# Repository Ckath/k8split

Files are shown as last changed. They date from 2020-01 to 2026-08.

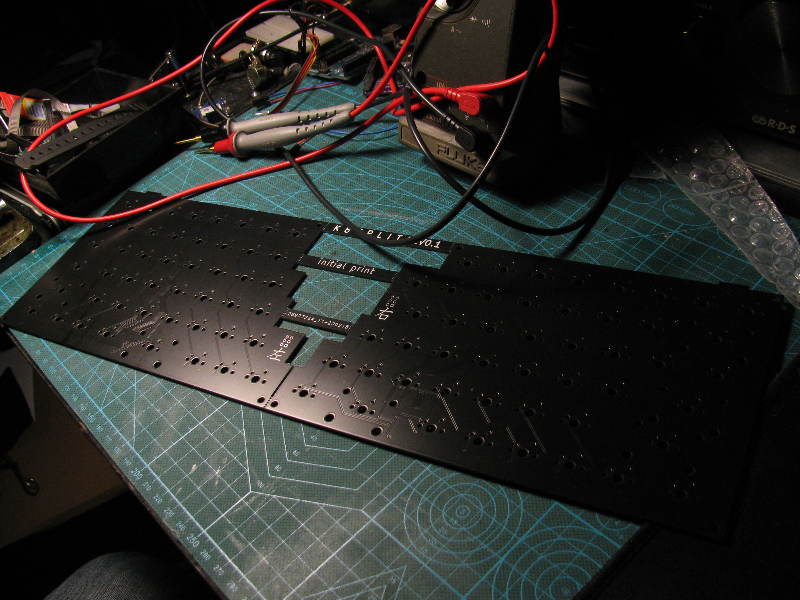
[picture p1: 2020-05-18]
k8split_board.jpg

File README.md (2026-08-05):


shoddy split keyboard for personal use, after ruining my [chinese split keyboard](http://xahlee.info/kbd/ly092_mini_keyboard.html) I attempted to recreate what I wanted from that, minus all the annoyances.

for the previous more scuffed and QMK version see [rev0.1](https://github.com/Ckath/k8split/tree/rev0.1)

## features
-  *normal* layout: 
	- no ortho
	- no lack of function row
	- no weird thumbclusters
	- plenty bonus keys to add what you miss
- no case or plate, only M3 holes
- halves are linked hardwired to central controller (over VGA)
- regular FULL SIZED USB PORT
- powered by TMK

## rev0.1->0.2 up/downgrades
- no more dual mcu nonsense
- no more QMK I'm not dealing with modern QMK
- no more smd 4 pin crystal suffering
- due to lack of pcb stabilizers for this formfactor: no more stabilizers
- cherry low profile switches
- boards themselves optimized for liquid damage mitigation, all throughhole for easy fixing

## pics
### keyboards
TODO
<!-- ![left](k8split_left.png) -->
<!-- ![right](k8split_right.png) -->
### pcb 
TODO
<!-- ![board](k8split_board.jpg) -->

## ordering
theres an `ORDER` folder in the pcb project, with all required files, dont honestly. if you want one I could probably send you one of my spare PCBs

### advice
keep in mind this is a personal board made just for myself, it's more up for reference/show than it is meant for people to actually use it. that said, some advice if you do think about making one:
- any still configured component part number is not updated, rev0.2 is made from what I had laying around and non pre assembled pcb
- to keep things easy I recommend a flat profile keycap set like dsa
- the nearly fully smd usb connector is a china find, you can find them on the regular places as "smd usb a female", the right ones should only have one shield pad on either side.
- the 'case' hardware used is a standard M3 standoff set, anything works.

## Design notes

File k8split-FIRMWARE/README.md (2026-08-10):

# TMK firmware
these are the minimal viable files for the tmk firmware to my best knowledge. attempted to be less horribly verbose in matrix.c implementation than most example boards, using only masks, avoiding needless extra functions etc.

## building/flashing
```
# if not already done, need this to get lufa repo inside tmk_core
git submodule update --init --recursive
# build and flash
make dfu
```

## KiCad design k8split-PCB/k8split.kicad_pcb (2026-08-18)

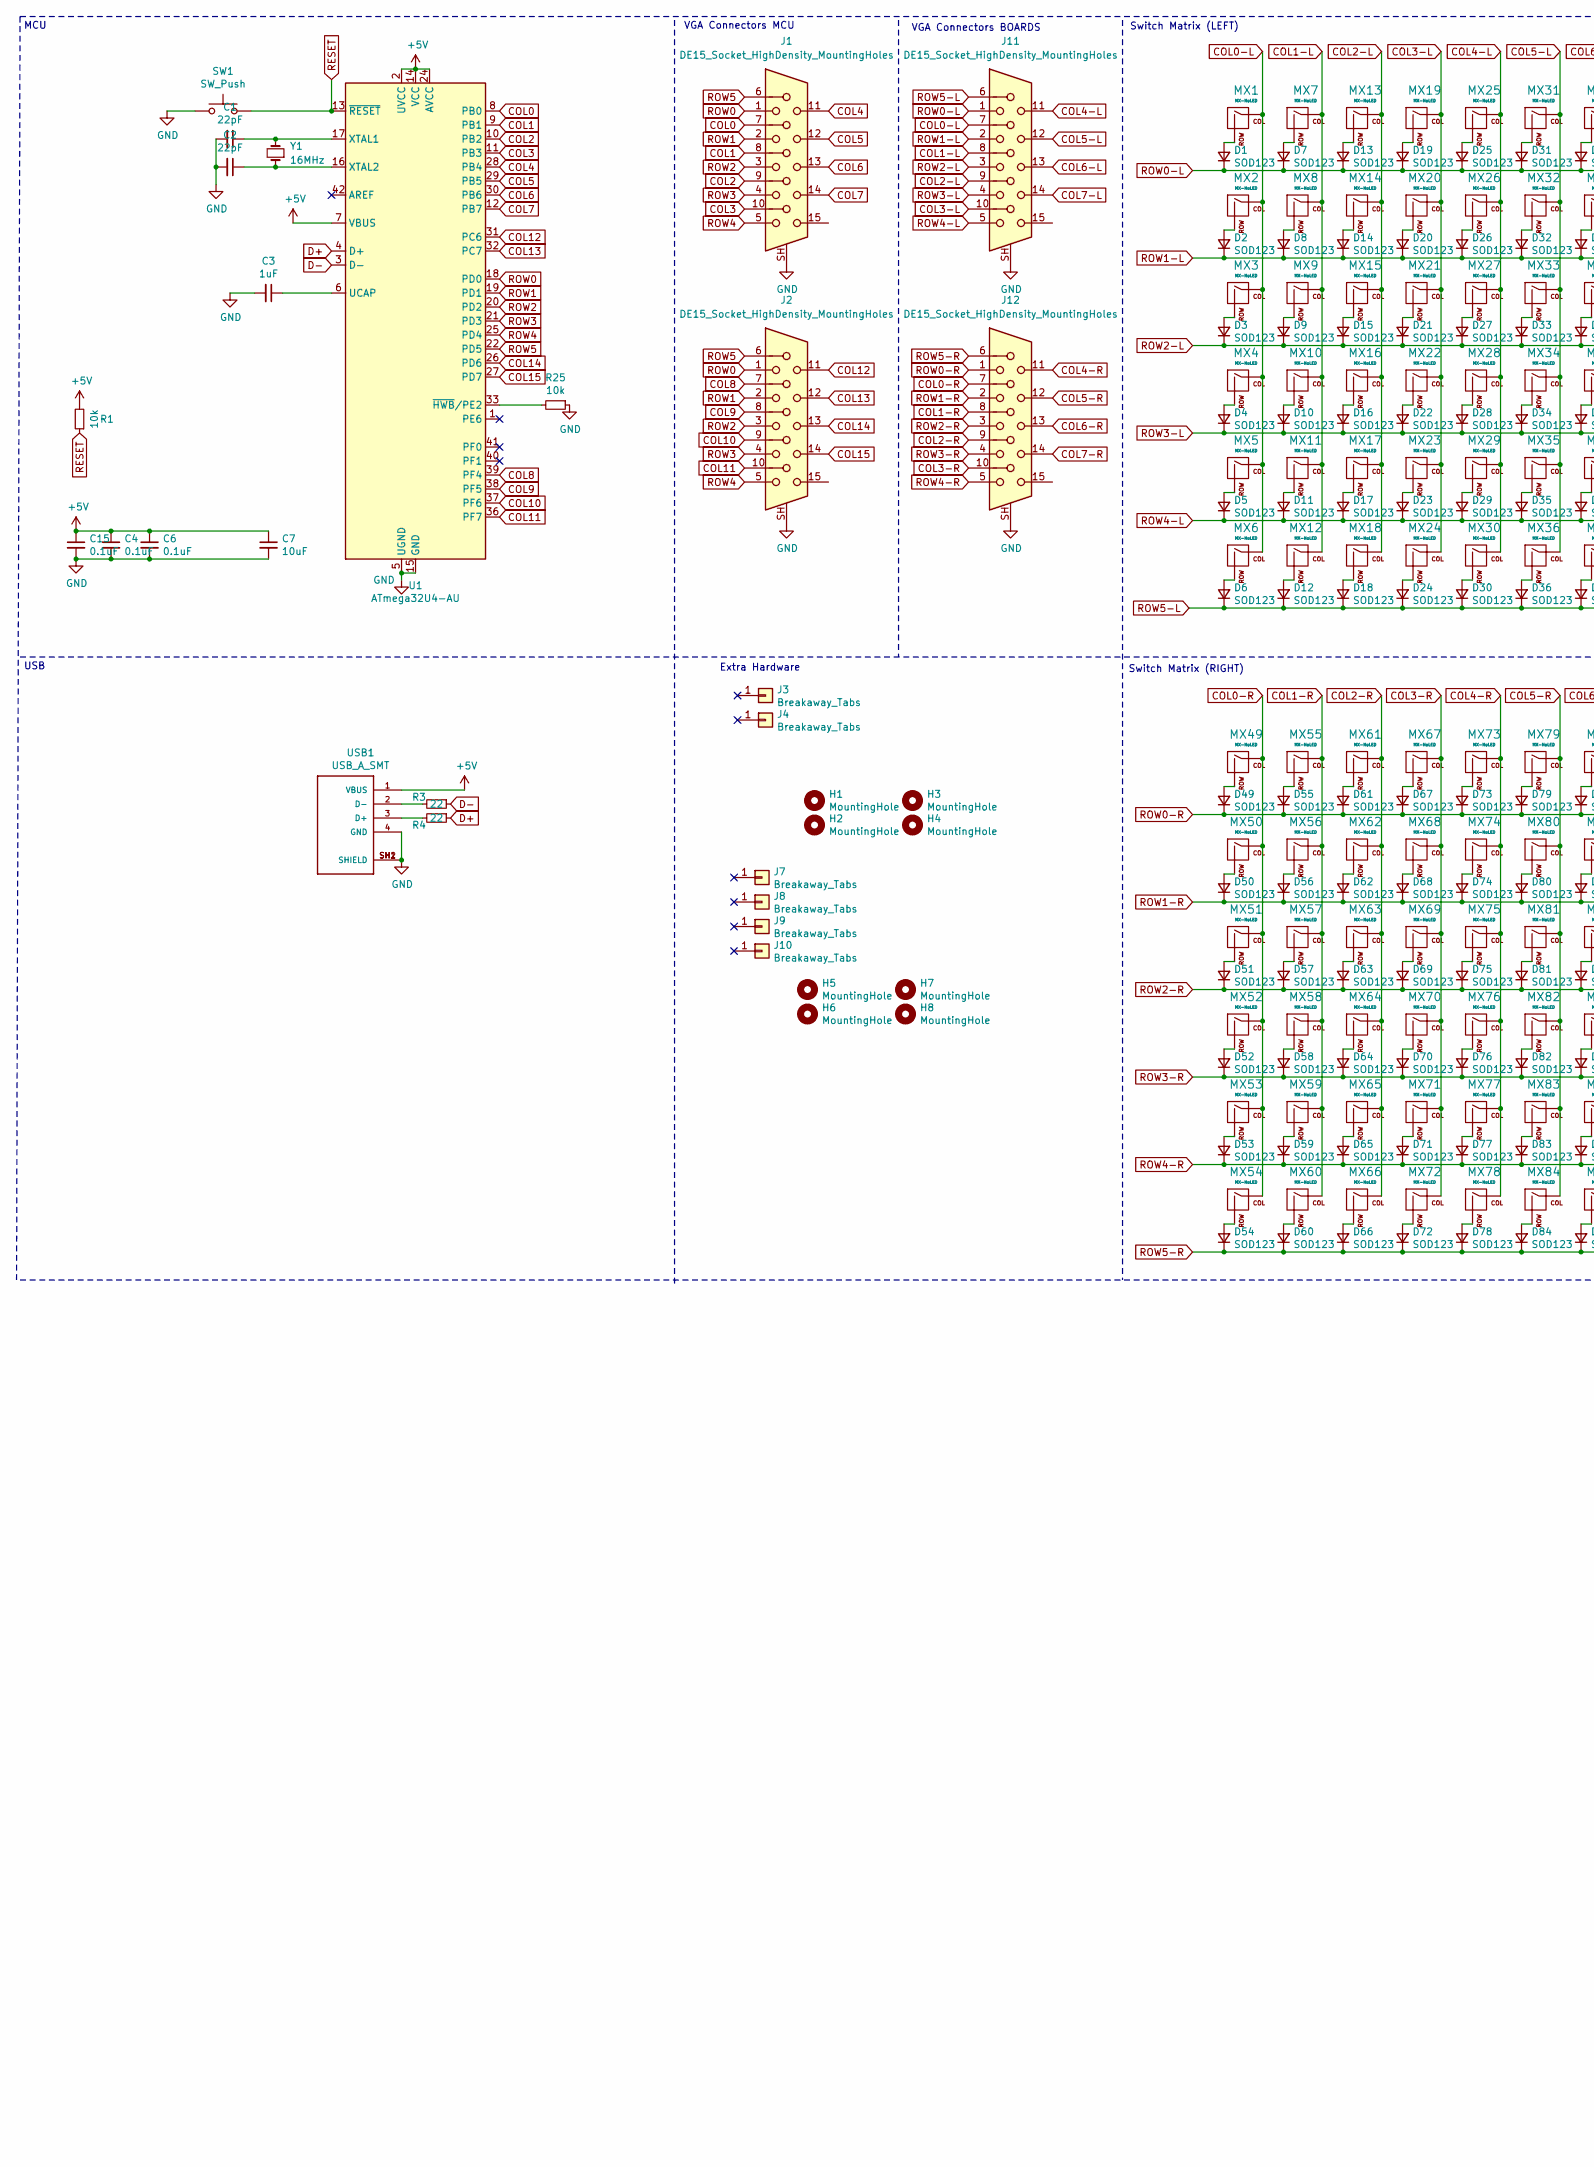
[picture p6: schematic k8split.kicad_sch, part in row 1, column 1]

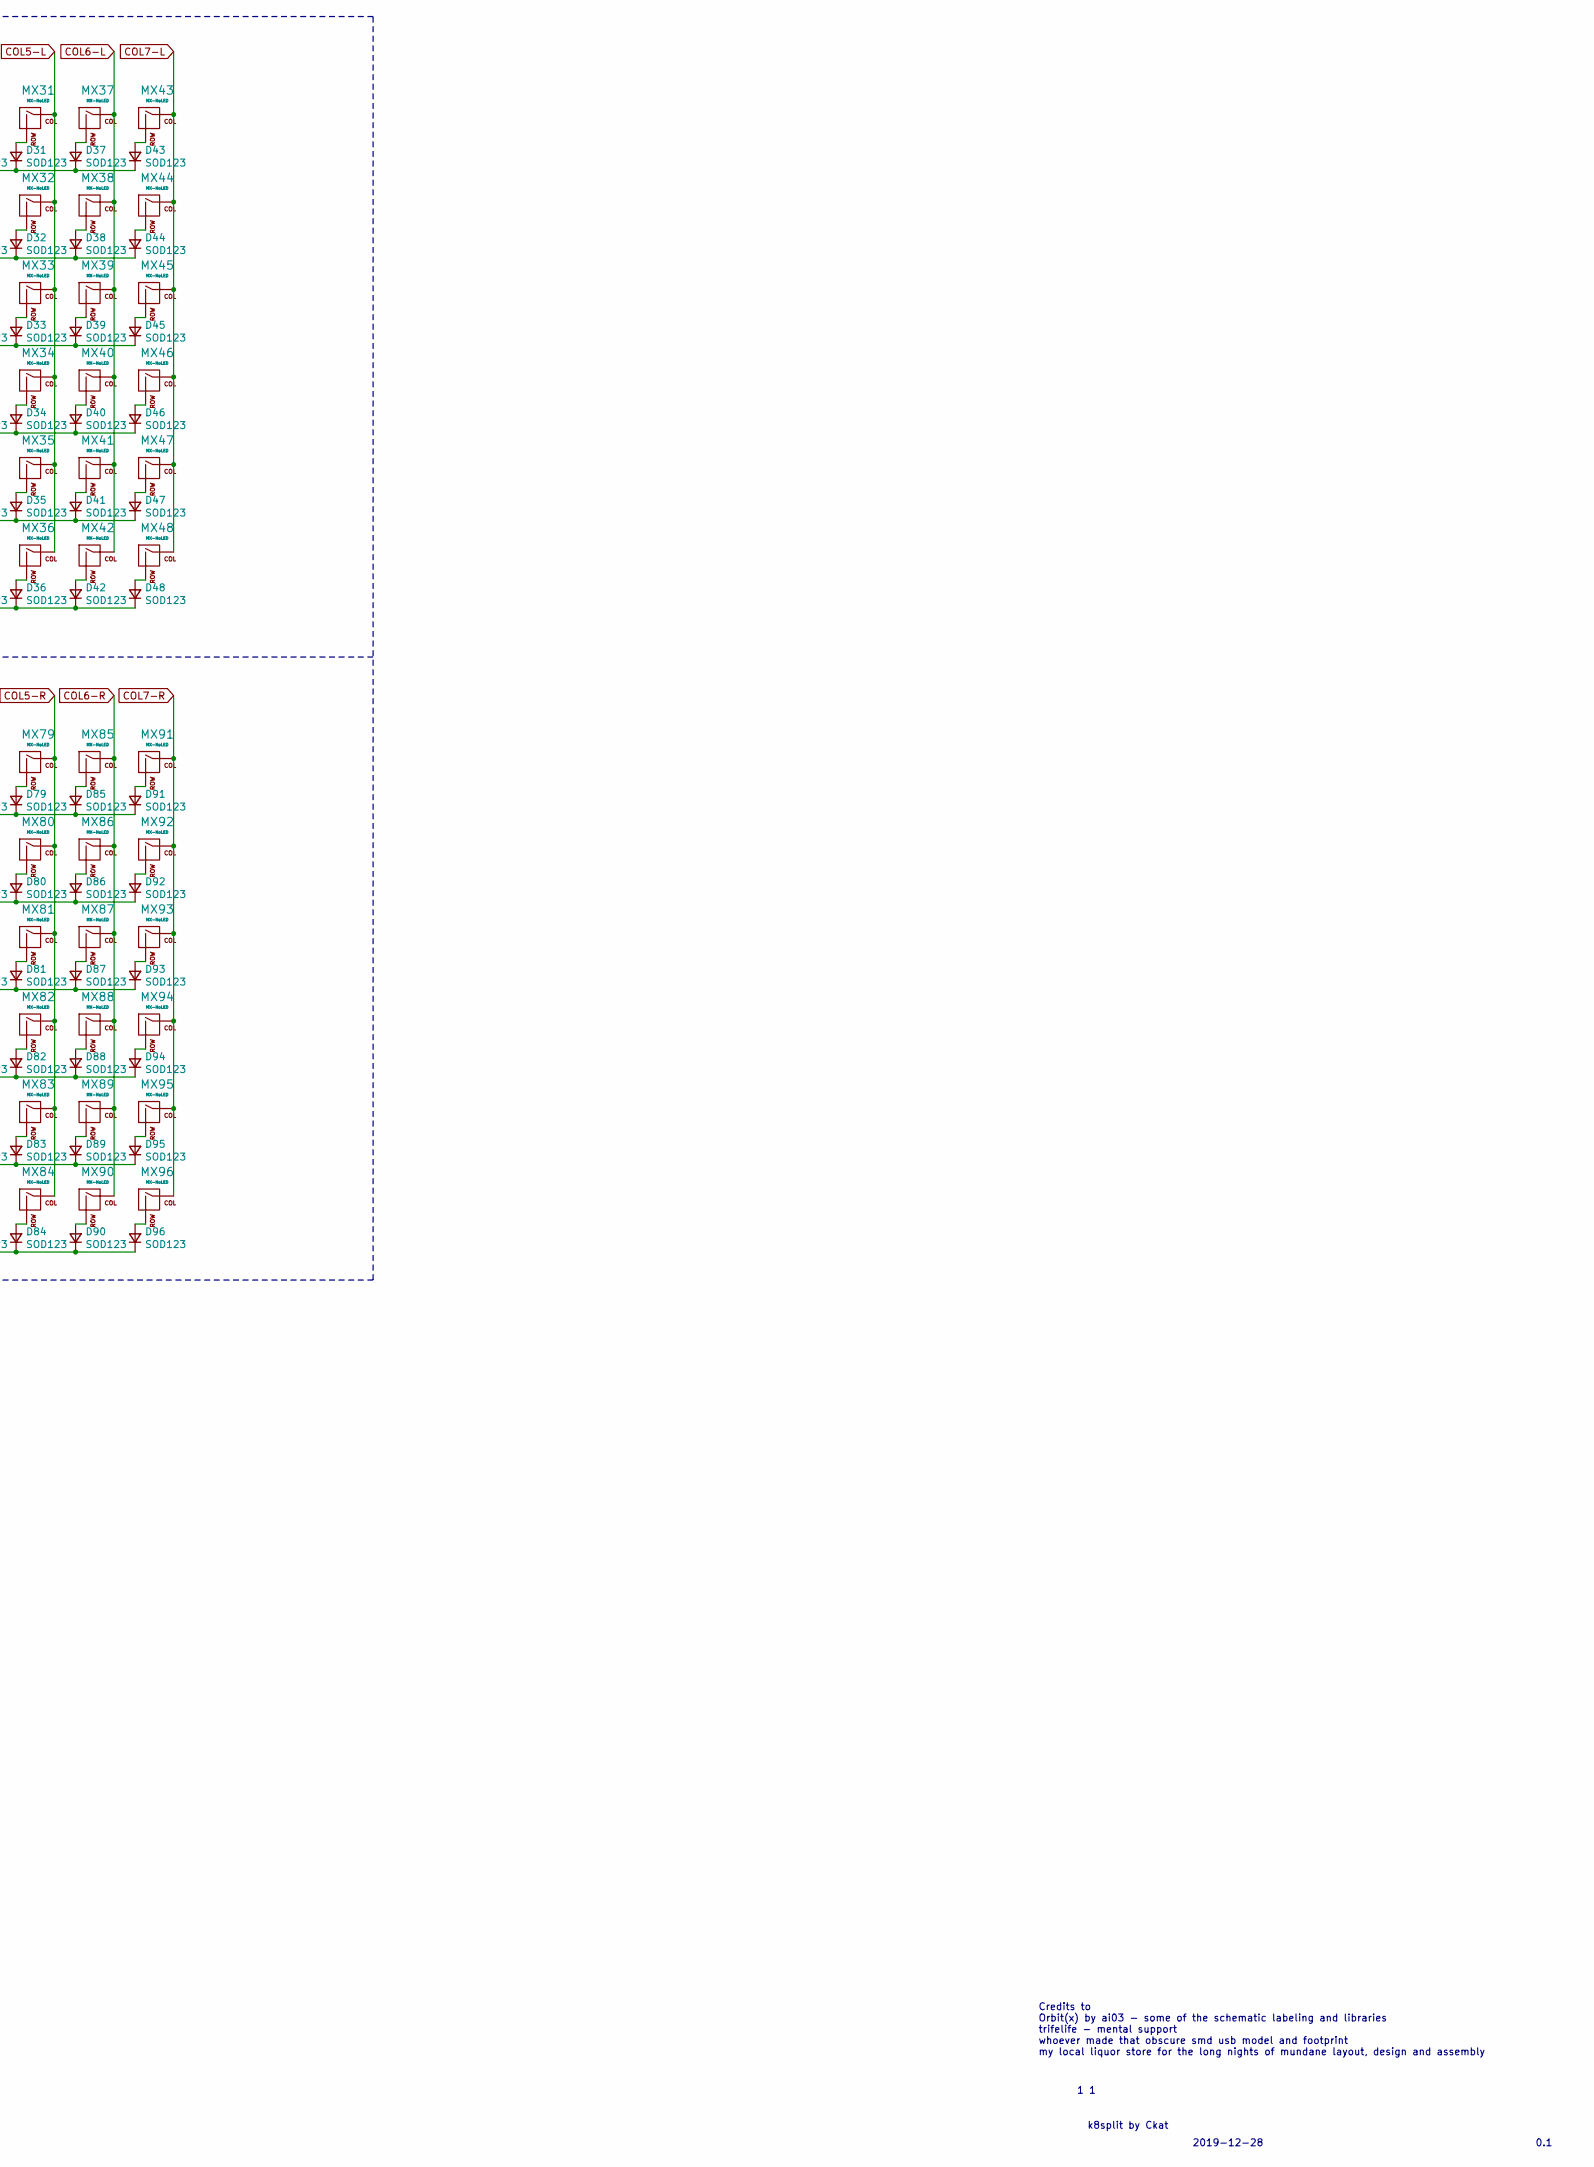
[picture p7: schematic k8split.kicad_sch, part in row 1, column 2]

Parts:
C1, C2: 22pF; C_0603_1608Metric
C3: 1uF; C_0603_1608Metric
C4, C6, C15: 0.1uF; C_0603_1608Metric
C7: 10uF; C_0603_1608Metric
D1, D2, D3, D4, D5, D6, D7, D8, D9, D10, D11, D12, D13, D14, D15, D16, D17, D18, D19, D20, D21, D22, D23, D24, D25, D26, D27, D28, D29, D30, D31, D32, D33, D34, D35, D36, D37, D38, D39, D40, D41, D42, D43, D44, D45, D46, D47, D48, D49, D50, D51, D52, D53, D54, D55, D56, D57, D58, D59, D60, D61, D62, D63, D64, D65, D66, D67, D68, D69, D70, D71, D72, D73, D74, D75, D76, D77, D78, D79, D80, D81, D82, D83, D84, D85, D86, D87, D88, D89, D90, D91, D92, D93, D94, D95, D96: SOD123; D_A-405_P10.16mm_Horizontal
H1, H2, H3, H4, H5, H6, H7, H8: MountingHole; MountingHole_3.2mm_M3
J1, J2, J11, J12: DE15_Socket_HighDensity_MountingHoles; DSUB-15-HD_Socket_Horizontal_P2.29x1.90mm_EdgePinOffset3.03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
J3, J4, J7, J8, J9, J10: Breakaway_Tabs; breakaway-mousebites
MX1, MX2, MX7, MX8, MX9, MX10, MX11, MX12, MX13, MX14, MX15, MX16, MX17, MX18, MX19, MX20, MX21, MX22, MX23, MX25, MX26, MX27, MX28, MX29, MX31, MX32, MX33, MX34, MX35, MX36, MX37, MX38, MX39, MX40, MX41, MX42, MX43, MX44, MX45, MX46, MX47, MX48, MX49, MX50, MX51, MX52, MX53, MX54, MX55, MX56, MX57, MX58, MX59, MX61, MX62, MX63, MX64, MX65, MX67, MX68, MX69, MX70, MX71, MX72, MX73, MX74, MX75, MX76, MX77, MX78, MX79, MX80, MX81, MX82, MX83, MX84, MX85, MX86, MX87, MX88, MX89, MX90, MX91: MX-NoLED; SW_choc_v2_1u
MX3, MX6, MX93, MX96: MX-NoLED; SW_choc_v2_1.5u
MX4: MX-NoLED; SW_choc_v2_1.75u
MX5, MX30, MX60, MX94: MX-NoLED; SW_choc_v2_2.25u
MX24, MX66: MX-NoLED; SW_choc_v2_1.25u
MX92: MX-NoLED; SW_choc_v2_2u
MX95: MX-NoLED; SW_choc_v2_2.75u
R1, R25: 10k; R_0603_1608Metric
R3, R4: 22; R_0603_1608Metric
SW1: SW_Push; SKQGADE010
U1: ATmega32U4-AU; TQFP-44_10x10mm_P0.8mm
USB1: USB_A_SMT; CUI_UJ2-AH-4-SMT
Y1: 16MHz; Crystal_HC49-4H_Vertical

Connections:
+5V: C4.1, C6.1, C7.1, C15.1, R1.2, U1.2 (UVCC), U1.7 (VBUS), U1.14 (VCC), U1.24 (AVCC), U1.34 (VCC), U1.44 (AVCC), USB1.1 (VBUS)
COL0: J1.7, U1.8 (PB0)
COL0-L: J11.7, MX1.1 (COL), MX2.1 (COL), MX3.1 (COL), MX4.1 (COL), MX5.1 (COL), MX6.1 (COL)
COL0-R: J12.7, MX49.1 (COL), MX50.1 (COL), MX51.1 (COL), MX52.1 (COL), MX53.1 (COL), MX54.1 (COL)
COL1: J1.8, U1.9 (PB1)
COL1-L: J11.8, MX7.1 (COL), MX8.1 (COL), MX9.1 (COL), MX10.1 (COL), MX11.1 (COL), MX12.1 (COL)
COL1-R: J12.8, MX55.1 (COL), MX56.1 (COL), MX57.1 (COL), MX58.1 (COL), MX59.1 (COL), MX60.1 (COL)
COL2: J1.9, U1.10 (PB2)
COL2-L: J11.9, MX13.1 (COL), MX14.1 (COL), MX15.1 (COL), MX16.1 (COL), MX17.1 (COL), MX18.1 (COL)
COL2-R: J12.9, MX61.1 (COL), MX62.1 (COL), MX63.1 (COL), MX64.1 (COL), MX65.1 (COL), MX66.1 (COL)
COL3: J1.10, U1.11 (PB3)
COL3-L: J11.10, MX19.1 (COL), MX20.1 (COL), MX21.1 (COL), MX22.1 (COL), MX23.1 (COL), MX24.1 (COL)
COL3-R: J12.10, MX67.1 (COL), MX68.1 (COL), MX69.1 (COL), MX70.1 (COL), MX71.1 (COL), MX72.1 (COL)
COL4: J1.11, U1.28 (PB4)
COL4-L: J11.11, MX25.1 (COL), MX26.1 (COL), MX27.1 (COL), MX28.1 (COL), MX29.1 (COL), MX30.1 (COL)
COL4-R: J12.11, MX73.1 (COL), MX74.1 (COL), MX75.1 (COL), MX76.1 (COL), MX77.1 (COL), MX78.1 (COL)
COL5: J1.12, U1.29 (PB5)
COL5-L: J11.12, MX31.1 (COL), MX32.1 (COL), MX33.1 (COL), MX34.1 (COL), MX35.1 (COL), MX36.1 (COL)
COL5-R: J12.12, MX79.1 (COL), MX80.1 (COL), MX81.1 (COL), MX82.1 (COL), MX83.1 (COL), MX84.1 (COL)
COL6: J1.13, U1.30 (PB6)
COL6-L: J11.13, MX37.1 (COL), MX38.1 (COL), MX39.1 (COL), MX40.1 (COL), MX41.1 (COL), MX42.1 (COL)
COL6-R: J12.13, MX85.1 (COL), MX86.1 (COL), MX87.1 (COL), MX88.1 (COL), MX89.1 (COL), MX90.1 (COL)
COL7: J1.14, U1.12 (PB7)
COL7-L: J11.14, MX43.1 (COL), MX44.1 (COL), MX45.1 (COL), MX46.1 (COL), MX47.1 (COL), MX48.1 (COL)
COL7-R: J12.14, MX91.1 (COL), MX92.1 (COL), MX93.1 (COL), MX94.1 (COL), MX95.1 (COL), MX96.1 (COL)
COL8: J2.7, U1.39 (PF4)
COL9: J2.8, U1.38 (PF5)
COL10: J2.9, U1.37 (PF6)
COL11: J2.10, U1.36 (PF7)
COL12: J2.11, U1.31 (PC6)
COL13: J2.12, U1.32 (PC7)
COL14: J2.13, U1.26 (PD6)
COL15: J2.14, U1.27 (PD7)
D+: R4.1, U1.4 (D+)
D-: R3.1, U1.3 (D-)
GND: C1.2, C2.2, C3.2, C4.2, C6.2, C7.2, C15.2, J1.SH, J2.SH, J11.SH, J12.SH, R25.1, SW1.1, U1.5 (UGND), U1.15 (GND), U1.23 (GND), U1.35 (GND), U1.43 (GND), USB1.4 (GND), USB1.SH1 (SHIELD), USB1.SH2 (SHIELD)
unnamed: D1.2 (A), MX1.2 (ROW)
unnamed: D2.2 (A), MX2.2 (ROW)
unnamed: D3.2 (A), MX3.2 (ROW)
unnamed: D4.2 (A), MX4.2 (ROW)
unnamed: D5.2 (A), MX5.2 (ROW)
unnamed: D6.2 (A), MX6.2 (ROW)
unnamed: D7.2 (A), MX7.2 (ROW)
unnamed: D8.2 (A), MX8.2 (ROW)
unnamed: D9.2 (A), MX9.2 (ROW)
unnamed: D10.2 (A), MX10.2 (ROW)
unnamed: D11.2 (A), MX11.2 (ROW)
unnamed: D12.2 (A), MX12.2 (ROW)
unnamed: D13.2 (A), MX13.2 (ROW)
unnamed: D14.2 (A), MX14.2 (ROW)
unnamed: D15.2 (A), MX15.2 (ROW)
unnamed: D16.2 (A), MX16.2 (ROW)
unnamed: D17.2 (A), MX17.2 (ROW)
unnamed: D18.2 (A), MX18.2 (ROW)
unnamed: D19.2 (A), MX19.2 (ROW)
unnamed: D20.2 (A), MX20.2 (ROW)
unnamed: D21.2 (A), MX21.2 (ROW)
unnamed: D22.2 (A), MX22.2 (ROW)
unnamed: D23.2 (A), MX23.2 (ROW)
unnamed: D24.2 (A), MX24.2 (ROW)
unnamed: D25.2 (A), MX25.2 (ROW)
unnamed: D26.2 (A), MX26.2 (ROW)
unnamed: D27.2 (A), MX27.2 (ROW)
unnamed: D28.2 (A), MX28.2 (ROW)
unnamed: D29.2 (A), MX29.2 (ROW)
unnamed: D30.2 (A), MX30.2 (ROW)
unnamed: D31.2 (A), MX31.2 (ROW)
unnamed: D32.2 (A), MX32.2 (ROW)
unnamed: D33.2 (A), MX33.2 (ROW)
unnamed: D34.2 (A), MX34.2 (ROW)
unnamed: D35.2 (A), MX35.2 (ROW)
unnamed: D36.2 (A), MX36.2 (ROW)
unnamed: D37.2 (A), MX37.2 (ROW)
unnamed: D38.2 (A), MX38.2 (ROW)
unnamed: D39.2 (A), MX39.2 (ROW)
unnamed: D40.2 (A), MX40.2 (ROW)
unnamed: D41.2 (A), MX41.2 (ROW)
unnamed: D42.2 (A), MX42.2 (ROW)
unnamed: D43.2 (A), MX43.2 (ROW)
unnamed: D44.2 (A), MX44.2 (ROW)
unnamed: D45.2 (A), MX45.2 (ROW)
unnamed: D46.2 (A), MX46.2 (ROW)
unnamed: D47.2 (A), MX47.2 (ROW)
unnamed: D48.2 (A), MX48.2 (ROW)
unnamed: D49.2 (A), MX49.2 (ROW)
unnamed: D50.2 (A), MX50.2 (ROW)
unnamed: D51.2 (A), MX51.2 (ROW)
unnamed: D52.2 (A), MX52.2 (ROW)
unnamed: D53.2 (A), MX53.2 (ROW)
unnamed: D54.2 (A), MX54.2 (ROW)
unnamed: D55.2 (A), MX55.2 (ROW)
unnamed: D56.2 (A), MX56.2 (ROW)
unnamed: D57.2 (A), MX57.2 (ROW)
unnamed: D58.2 (A), MX58.2 (ROW)
unnamed: D59.2 (A), MX59.2 (ROW)
unnamed: D60.2 (A), MX60.2 (ROW)
unnamed: D61.2 (A), MX61.2 (ROW)
unnamed: D62.2 (A), MX62.2 (ROW)
unnamed: D63.2 (A), MX63.2 (ROW)
unnamed: D64.2 (A), MX64.2 (ROW)
unnamed: D65.2 (A), MX65.2 (ROW)
unnamed: D66.2 (A), MX66.2 (ROW)
unnamed: D67.2 (A), MX67.2 (ROW)
unnamed: D68.2 (A), MX68.2 (ROW)
unnamed: D69.2 (A), MX69.2 (ROW)
unnamed: D70.2 (A), MX70.2 (ROW)
unnamed: D71.2 (A), MX71.2 (ROW)
unnamed: D72.2 (A), MX72.2 (ROW)
unnamed: D73.2 (A), MX73.2 (ROW)
unnamed: D74.2 (A), MX74.2 (ROW)
unnamed: D75.2 (A), MX75.2 (ROW)
unnamed: D76.2 (A), MX76.2 (ROW)
unnamed: D77.2 (A), MX77.2 (ROW)
unnamed: D78.2 (A), MX78.2 (ROW)
unnamed: D79.2 (A), MX79.2 (ROW)
unnamed: D80.2 (A), MX80.2 (ROW)
unnamed: D81.2 (A), MX81.2 (ROW)
unnamed: D82.2 (A), MX82.2 (ROW)
unnamed: D83.2 (A), MX83.2 (ROW)
unnamed: D84.2 (A), MX84.2 (ROW)
unnamed: D85.2 (A), MX85.2 (ROW)
unnamed: D86.2 (A), MX86.2 (ROW)
unnamed: D87.2 (A), MX87.2 (ROW)
unnamed: D88.2 (A), MX88.2 (ROW)
unnamed: D89.2 (A), MX89.2 (ROW)
unnamed: D90.2 (A), MX90.2 (ROW)
unnamed: D91.2 (A), MX91.2 (ROW)
unnamed: D92.2 (A), MX92.2 (ROW)
unnamed: D93.2 (A), MX93.2 (ROW)
unnamed: D94.2 (A), MX94.2 (ROW)
unnamed: D95.2 (A), MX95.2 (ROW)
unnamed: D96.2 (A), MX96.2 (ROW)
unnamed: C3.1, U1.6 (UCAP)
unnamed: C1.1, U1.17 (XTAL1), Y1.2
unnamed: C2.1, U1.16 (XTAL2), Y1.1
unnamed: R25.2, U1.33 (~HWB/PE2)
unnamed: R4.2, USB1.3 (D+)
unnamed: R3.2, USB1.2 (D-)
RESET: R1.1, SW1.2, U1.13 (~RESET)
ROW0: J1.1, J2.1, U1.18 (PD0)
ROW0-L: D1.1 (K), D7.1 (K), D13.1 (K), D19.1 (K), D25.1 (K), D31.1 (K), D37.1 (K), D43.1 (K), J11.1
ROW0-R: D49.1 (K), D55.1 (K), D61.1 (K), D67.1 (K), D73.1 (K), D79.1 (K), D85.1 (K), D91.1 (K), J12.1
ROW1: J1.2, J2.2, U1.19 (PD1)
ROW1-L: D2.1 (K), D8.1 (K), D14.1 (K), D20.1 (K), D26.1 (K), D32.1 (K), D38.1 (K), D44.1 (K), J11.2
ROW1-R: D50.1 (K), D56.1 (K), D62.1 (K), D68.1 (K), D74.1 (K), D80.1 (K), D86.1 (K), D92.1 (K), J12.2
ROW2: J1.3, J2.3, U1.20 (PD2)
ROW2-L: D3.1 (K), D9.1 (K), D15.1 (K), D21.1 (K), D27.1 (K), D33.1 (K), D39.1 (K), D45.1 (K), J11.3
ROW2-R: D51.1 (K), D57.1 (K), D63.1 (K), D69.1 (K), D75.1 (K), D81.1 (K), D87.1 (K), D93.1 (K), J12.3
ROW3: J1.4, J2.4, U1.21 (PD3)
ROW3-L: D4.1 (K), D10.1 (K), D16.1 (K), D22.1 (K), D28.1 (K), D34.1 (K), D40.1 (K), D46.1 (K), J11.4
ROW3-R: D52.1 (K), D58.1 (K), D64.1 (K), D70.1 (K), D76.1 (K), D82.1 (K), D88.1 (K), D94.1 (K), J12.4
ROW4: J1.5, J2.5, U1.25 (PD4)
ROW4-L: D5.1 (K), D11.1 (K), D17.1 (K), D23.1 (K), D29.1 (K), D35.1 (K), D41.1 (K), D47.1 (K), J11.5
ROW4-R: D53.1 (K), D59.1 (K), D65.1 (K), D71.1 (K), D77.1 (K), D83.1 (K), D89.1 (K), D95.1 (K), J12.5
ROW5: J1.6, J2.6, U1.22 (PD5)
ROW5-L: D6.1 (K), D12.1 (K), D18.1 (K), D24.1 (K), D30.1 (K), D36.1 (K), D42.1 (K), D48.1 (K), J11.6
ROW5-R: D54.1 (K), D60.1 (K), D66.1 (K), D72.1 (K), D78.1 (K), D84.1 (K), D90.1 (K), D96.1 (K), J12.6

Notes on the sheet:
VGA Connectors BOARDS
VGA Connectors MCU
Extra Hardware
Credits to Orbit(x) by ai03 - some of the schematic labeling and libraries trifelife - mental support whoever made that obscure smd usb model and footprint my local liquor store for the long nights of mundane layout, design and assembly
1 1
MCU
0.1
k8split by Ckat
Switch Matrix (RIGHT)
USB
2019-12-28
Switch Matrix (LEFT)

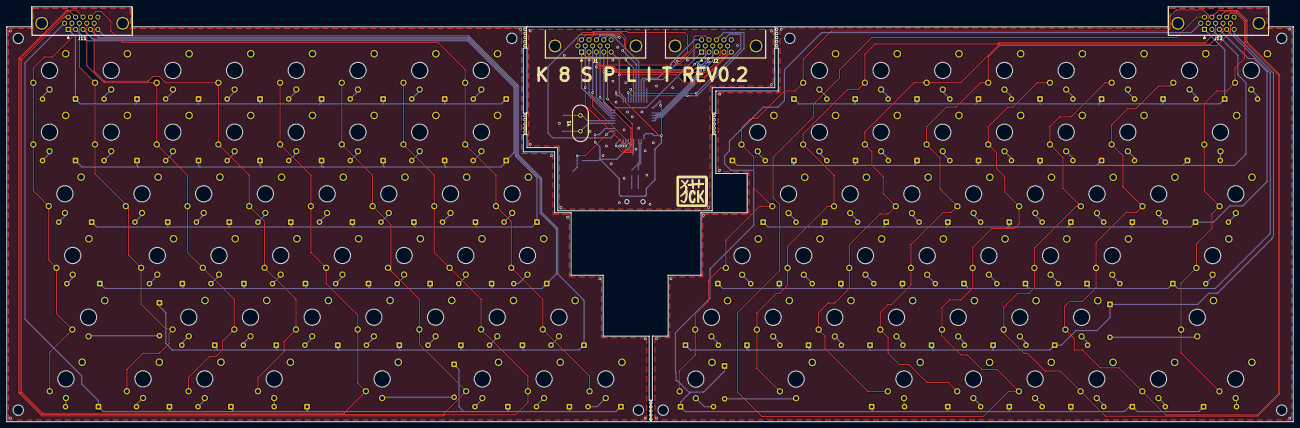
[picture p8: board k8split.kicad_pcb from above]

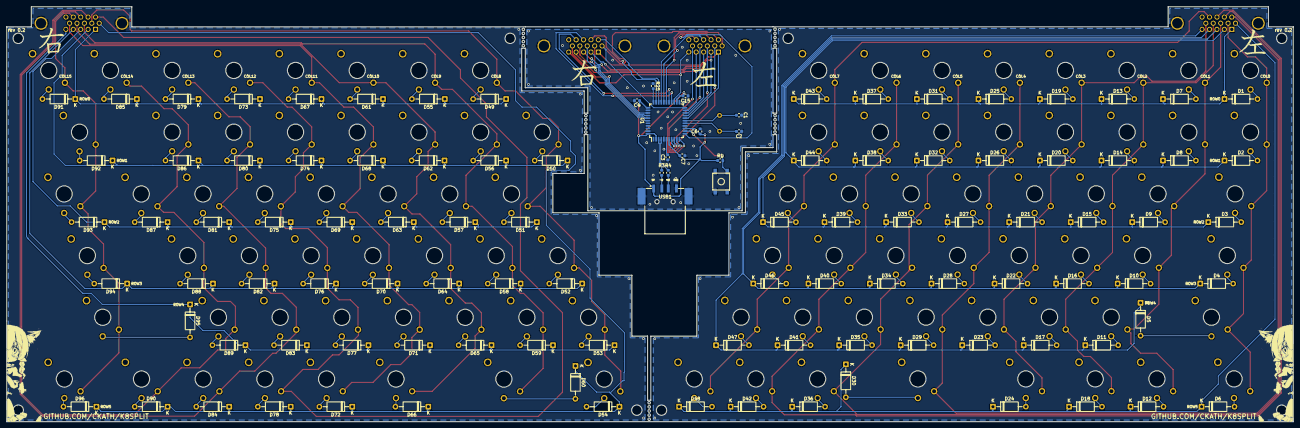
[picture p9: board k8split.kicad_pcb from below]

Board: 2 copper layers, 397.3 x 128.1 mm, 224 parts (110 on the bottom side), 157 nets.

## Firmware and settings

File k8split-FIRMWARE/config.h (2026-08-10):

/* MIT License

Copyright (c) 2026 Ckat <Ckath@yandex.ru>

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
THE SOFTWARE IS PROVIDED "AS IS", WITHOUT WARRANTY OF ANY KIND, EXPRESS OR
IMPLIED, INCLUDING BUT NOT LIMITED TO THE WARRANTIES OF MERCHANTABILITY,
FITNESS FOR A PARTICULAR PURPOSE AND NONINFRINGEMENT. IN NO EVENT SHALL THE
AUTHORS OR COPYRIGHT HOLDERS BE LIABLE FOR ANY CLAIM, DAMAGES OR OTHER
LIABILITY, WHETHER IN AN ACTION OF CONTRACT, TORT OR OTHERWISE, ARISING FROM,
OUT OF OR IN CONNECTION WITH THE SOFTWARE OR THE USE OR OTHER DEALINGS IN THE
SOFTWARE.
*/
#ifndef CONFIG_H
#define CONFIG_H

/* USB Device descriptor parameter */
#define VENDOR_ID       0xC81D
#define PRODUCT_ID      0xC868
#define DEVICE_VER      0x0002
#define MANUFACTURER    Ckat 
#define PRODUCT         k8split
#define DESCRIPTION     rev0.2

/* key matrix size */
#define MATRIX_ROWS 6
#define MATRIX_COLS 16

/* ROW/COL MASKS */
#define ROW_MASK  0b00111111 /* PD0-PD5 row0-row5 */
#define COLB_MASK 0b11111111 /* PB0-PB7 col0-col7 */
#define COLF_MASK 0b11110000 /* PF4-PF6 col8-col11 */
#define COLC_MASK 0b11000000 /* PC6-PF7 col12-col13 */
#define COLD_MASK 0b11000000 /* PD6-PD7 col14-col15 */

/* can get away with lower since silent choc v2 */
#define DEBOUNCE 3

/* disable action features */
#define NO_ACTION_LAYER
#define NO_ACTION_TAPPING
#define NO_ACTION_ONESHOT
#define NO_ACTION_MACRO
#define NO_ACTION_FUNCTION

#endif

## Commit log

2020-01-13 near completed routing on boards
    [k8split.kicad_pcb, k8split.sch]
2020-01-17 add some branding to pcb
    [k8split.kicad_pcb]
2020-01-19 small board redesign regarding usb, start fixing silkscreen
    [k8split.kicad_pcb]
2020-01-22 initial panelizing
    [k8split.kicad_pcb, k8split.sch]
2020-01-23 finish panelizing pcb
    [k8split.kicad_pcb]
2020-01-25 initial gerber files
    [JLCSMT_Sample_BOM1.xlsx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]
2020-01-26 add jlc bom, move switches
    - all part numbers found on jlc, might change some packages later
    - move switches to other side because smd manufacturing is one side
    - gerbers not regenerated, more changes to be done before doing it again
    [JLCSMT_Sample_BOM1.xlsx, k8split.csv, k8split.kicad_pcb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]
2020-01-26 cleaned up libs and parts
    - switched out 0805 resistors to 0603
    - deleted some unused libraries
    - re-associated symbols libs to point to system ones
    [k8split-B_Cu.gbl, k8split-B_Mask.gbs, k8split-B_Paste.gbp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]
2020-01-28 redid some silkscreen, cleaned up button move
    [k8split.kicad_pcb]
2020-01-29 move silk on avr connectors
    [k8split.kicad_pcb]
2020-01-31 add silk for usb pins very uuseful
    [k8split.kicad_pcb]
2020-02-01 avr program header typesetting wwow
    [k8split.kicad_pcb]
2020-02-10 add some corona jokes
    [k8split.kicad_pcb]
2020-02-11 trace cleanup
    [k8split.kicad_pcb]
2020-02-11 more trace cleanup
    [k8split.kicad_pcb]
2020-02-17 further pcb project cleanup
    [JLCSMT_Sample_BOM1.xlsx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]
2020-05-18 update some minor schmetatic details
    [k8split.sch]
2026-08-05 pcb update for rev0.2
    [JLCSMT_Sample_BOM1.xlsx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]
2026-08-10 remove debounce define sanity check
    I'd rather it crash than behave differently
    [matrix.c]
2026-08-11 cleanup makefile
    also remove interrupt setting, seems to allow interruption of matrix
    scanning for minimal benefits. can only see it cause issues
2026-08-17 last minute drc fixes
    - unconnected row pins
    - unconnected keys
    - unconnected reset
    - unconnected vcc
    - moved around decoupling caps a bit
    [k8split.kicad_pcb]
2026-08-18 final order data update
    [k8split-B_Cu.gbl, k8split-B_Mask.gbs, k8split-B_Paste.gbp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]
